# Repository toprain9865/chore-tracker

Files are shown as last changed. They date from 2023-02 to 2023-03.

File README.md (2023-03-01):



# Chore Tracker

A device to track up to 5 chores around the house. I am currently tracking my clothes washer, clothes dryer, dishwasher, trash, and recycling. The indicators are WS2812 LEDs, allowing customization of the indicator colors, patterns, etc.

I have additionally included a DHT22 temperature and humidity sensor.

## Code

I used ESPHome and Home Assistant to do all the heavy lifting. You can find the basic code to get everything on the PCB into an ESPHome configuration.

## Body

The body is deep enough to comfortably hold all the components as well as a generous amount of extra wire, in case you don't want to deal with getting everything the perfect length and just so. The hole in the model for the USB cord will fit a cord, but won't fit a terminated cord. You'll have to pull it through and then add the JST connector.

## PCB

When soldering the PCB, don't skimp out on the pin sockets. Both the ground and power planes are directly under the antenna, which isn't a performance issue if you use the pin sockets to get enough of a separation. I don't know how it might work if you solder it directly to the board.

I also designed the PCB to include a potentiometer to control the brightness of the LEDs. I ended up not using it, and instead just programming a fixed brightness that works well for me. Optional components for the potentiometer are listed below *in italics*.

## BOM

|Qty|Description|P/N|
|-|-|-|
|1|PCB|
1|Printed case
1|USB power cable|
|2|JST connector, 1x3, 2.54mm pitch
|2|JST PCB header, 1x3, 2.54mm pitch
6|JST connector, 1x2, 2.54mm pitch
6|JST PCB header, 1x2, 2.54mm pitch
1|esp8266 microcontroller|WeMos D1 mini
1|I<sup>2</sup>C I/O expander|MCP23008
1|DIP18 IC socket
2|10k resistor, 1/4 W, axial, len: 9.0mm, dia: 3.2mm
5|SPST momentary push button, 6mm cap, 6.9mm thread
5|WS2812B 5050 neopixel LEDs with PCB|
1|DHT22 compatible temperature & humidity sensor|AM2302
1|*JST connector, 1x3, 2.54mm pitch*
1|*JST PCB header, 1x3, 2.54mm pitch*
1|*Potentiometer*

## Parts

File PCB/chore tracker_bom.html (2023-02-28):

Source File | chore tracker.kicad_sch
BoM Date | 7/29/2022 11:06:05 AM
Schematic Version | 1.2
Schematic Date | 2022-07-29
PCB Variant | default
KiCad Version | Eeschema (6.0.5)
Component Groups | 5
Component Count (per PCB) | 13
Fitted Components (per PCB) | 13
Number of PCBs | 1
Total Component Count (for 1 PCBs) | 13
References | Description | Part | Value | Footprint | Qty
J107 J108 J109 | Generic connector, single row, 01x03, script generated (kicad-library-utils/schlib/autogen/connector/) | Conn_01x03 | NEOPIXEL_BUS | JST_XH_B3B-XH-AM_1x03_P2.50mm_Vertical | 3
J101 J102 J103 J104 J105 J106 | Generic connector, single row, 01x02, script generated (kicad-library-utils/schlib/autogen/connector/) | Conn_01x02 | PWR_IN | JST_XH_B2B-XH-AM_1x02_P2.50mm_Vertical | 6
R101 R102 | Resistor | R | 10k | R_Axial_DIN0309_L9.0mm_D3.2mm_P2.54mm_Vertical | 2
U102 | 8-bit I/O expander, I2C, interrupts, PDIP-18 | MCP23008-xP | MCP23008-xP | DIP-18_W7.62mm | 1
U101 | 32-bit microcontroller module with WiFi | WeMos_D1_mini | WeMos_D1_mini | WEMOS_D1_mini_light | 1

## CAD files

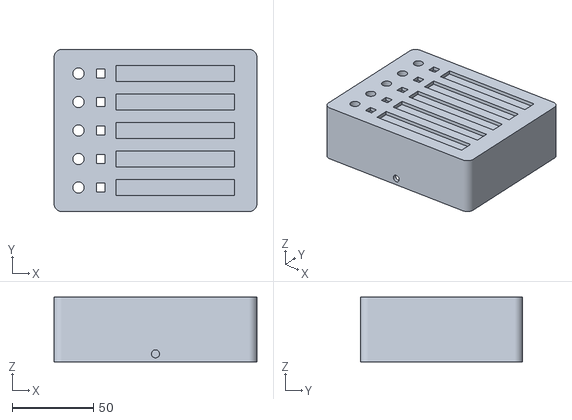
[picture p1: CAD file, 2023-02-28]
3D Model/chore tracker-Body.stl
125.0 x 100.0 x 40.0

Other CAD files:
3D Model/chore tracker.FCStd

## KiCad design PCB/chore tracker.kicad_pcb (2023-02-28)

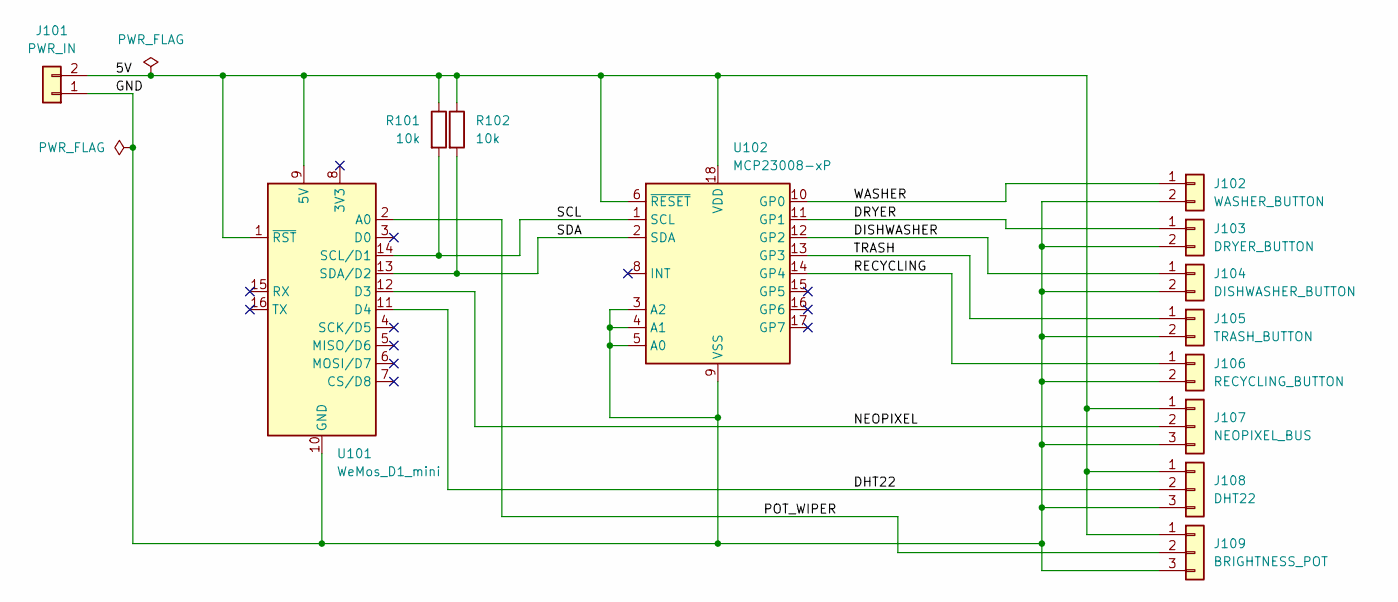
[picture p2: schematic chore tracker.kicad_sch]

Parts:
J101: PWR_IN; JST_XH_B2B-XH-AM_1x02_P2.50mm_Vertical
J102: WASHER_BUTTON; JST_XH_B2B-XH-AM_1x02_P2.50mm_Vertical
J103: DRYER_BUTTON; JST_XH_B2B-XH-AM_1x02_P2.50mm_Vertical
J104: DISHWASHER_BUTTON; JST_XH_B2B-XH-AM_1x02_P2.50mm_Vertical
J105: TRASH_BUTTON; JST_XH_B2B-XH-AM_1x02_P2.50mm_Vertical
J106: RECYCLING_BUTTON; JST_XH_B2B-XH-AM_1x02_P2.50mm_Vertical
J107: NEOPIXEL_BUS; JST_XH_B3B-XH-AM_1x03_P2.50mm_Vertical
J108: DHT22; JST_XH_B3B-XH-AM_1x03_P2.50mm_Vertical
J109: BRIGHTNESS_POT; JST_XH_B3B-XH-AM_1x03_P2.50mm_Vertical
R101, R102: 10k; R_Axial_DIN0309_L9.0mm_D3.2mm_P2.54mm_Vertical
U101: WeMos_D1_mini; WEMOS_D1_mini_light
U102: MCP23008-xP; DIP-18_W7.62mm

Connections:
/5V: J101.2, J107.1, J108.1, J109.1, R101.1, R102.1, U101.1 (~RST), U101.9 (5V), U102.6 (~RESET), U102.18 (VDD)
/DHT22: J108.2, U101.11 (D4)
/DISHWASHER: J104.1, U102.12 (GP2)
/DRYER: J103.1, U102.11 (GP1)
/GND: J101.1, J102.2, J103.2, J104.2, J105.2, J106.2, J107.3, J108.3, J109.3, U101.10 (GND), U102.3 (A2), U102.4 (A1), U102.5 (A0), U102.9 (VSS)
/NEOPIXEL: J107.2, U101.12 (D3)
/POT_WIPER: J109.2, U101.2 (A0)
/RECYCLING: J106.1, U102.14 (GP4)
/SCL: R101.2, U101.14 (SCL/D1), U102.1 (SCL)
/SDA: R102.2, U101.13 (SDA/D2), U102.2 (SDA)
/TRASH: J105.1, U102.13 (GP3)
/WASHER: J102.1, U102.10 (GP0)

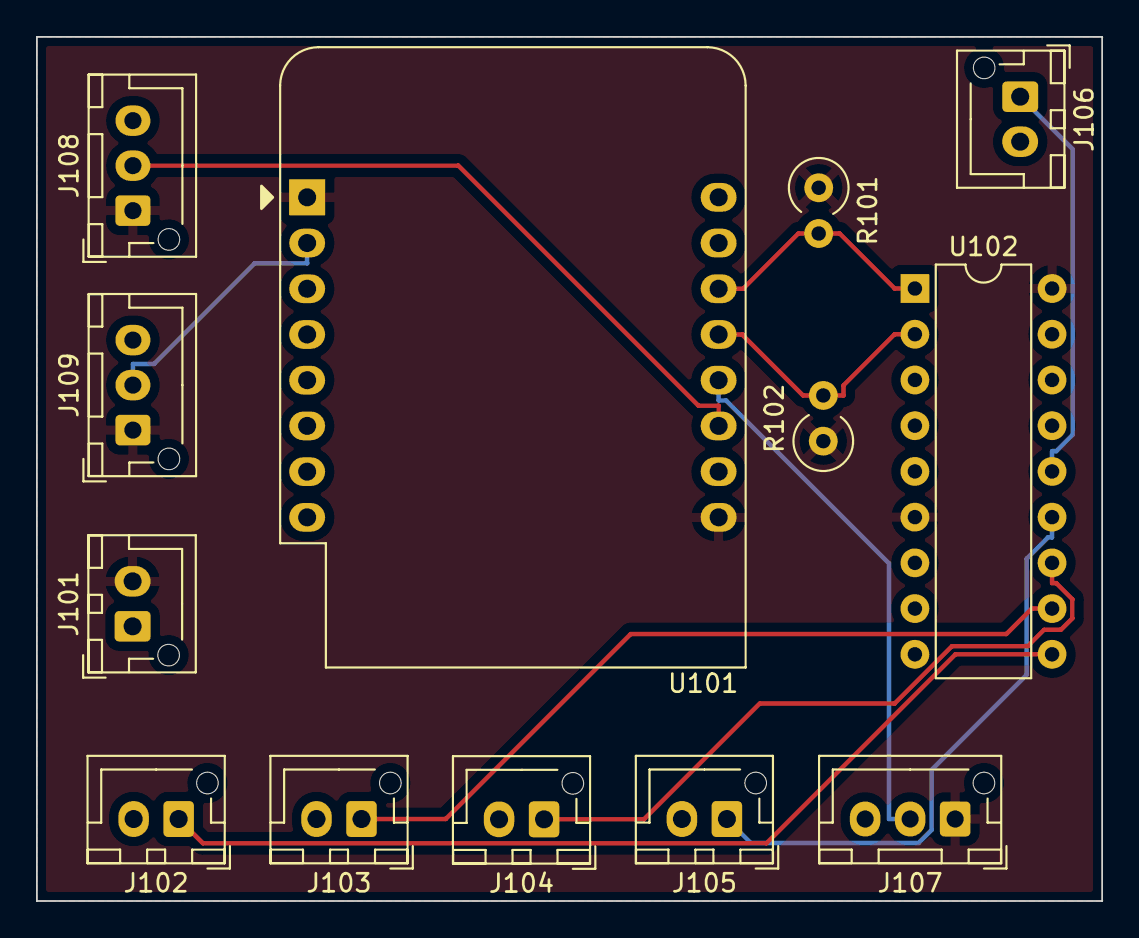
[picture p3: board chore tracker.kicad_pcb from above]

Board: 2 copper layers, 59.2 x 48.0 mm, 13 parts (0 on the bottom side), 12 nets.

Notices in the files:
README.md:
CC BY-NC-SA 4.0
